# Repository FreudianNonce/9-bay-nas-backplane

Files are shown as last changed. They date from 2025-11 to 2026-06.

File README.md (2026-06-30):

# DIY 9-Bay NAS Backplane

> A simple and compact 9-Bay Backplance for a compact NAS application.

## Overview

This backplane is designed for connectivity for up to 8 SATA 3.0 storage drives connected to a PCIE HBA, as well as one slot for a SATA 3.0 boot drive connected to a motherboard SATA header. This board was specifically designed to be used in a Fractal Terra with an HDPLEX 250w GaN PSU, but should work for any small form factor NAS.

## Specifications

Dimensions: 115mmx58mm
Power Connector: 4-pin peripheral
Supply Voltage: 5v
Hot Swap: Hardware Supported (HBA must also support)

## Project Status

We've reached version 1.2 of this project. It took longer than I hoped, but I've built and tested this version and am currently running it in my NAS.

## Changes

Changes since version 1.0 include the following

- updated power connector to 4-pin peripheral (goodbye screw terminal)
- updated bulk capacitors to an appropriate size
- removed the 12v rail (only 5v is needed for SSDs)
- added full ground plane
- fixed SATA Data differential pair balancing
- added large isolation zone

## Making

Actually making one of these backplanes is very tedious. I can only recommend this if you have fine soldering skills.

If you do decide to make this, this is how I assembeled it.

- solder the SMD capacitors and resistors first. It is recommended that you use a solder reflow station. 
- for SATA interfaces, start on the end of the board that is furthest away from the power through holes
- use two 22-pin SATA connectors (one on J901 and one on J101, for balance), solder J901
- flip the board over and use three 7-pin SATA connectors (one on J902, J102, and the edge of the board where its falling over), solder J902
- flip the board over and repeat for all slots in descending order.
- once all the slots are soldered, solder the bulk capacitors, and 4-pin power. order doesnt matter here

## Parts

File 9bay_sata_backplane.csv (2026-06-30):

Reference | Qty | Value | DNP | Exclude from BOM | Exclude from Board | Footprint | Datasheet
C1,C2 | 2 | 25v 560uf |  |  |  | Capacitor_THT:CP_Radial_D10.0mm_P5.00mm | https://www.mouser.com/ProductDetail/Panasonic/EEH-AZS1E561B?qs=81r%252BiQLm7BR3Lrx9nkxErQ%3D%3D
C101,C201,C301,C401,C501,C601,C701,C801,C901 | 9 | 35v 10uf |  |  |  | Capacitor_SMD:C_1206_3216Metric | https://www.mouser.com/ProductDetail/Samsung-Electro-Mechanics/CL31B106KLHNNNE?qs=yOVawPpwOwktbQXOrUt5Og%3D%3D
J1 | 1 | HDD POWER |  |  |  | Connector_TE-Connectivity:TE_MATE-N-LOK_350211-1_1x04_P5.08mm_Vertical | https://www.mouser.com/ProductDetail/TE-Connectivity-AMP/350211-1
J101,J201,J301,J401,J501,J601,J701,J801,J901 | 9 | 87779-1001 |  |  |  | 87779-1001:877791001 | https://www.mouser.com/ProductDetail/Molex/87779-1001?qs=D%252By4jQJzx8JOwxiJNs7sKQ%3D%3D
J102,J202,J302,J402,J502,J602,J702,J802,J902 | 9 | 67800-8025 |  |  |  | 67800-8025:678008025 | https://www.mouser.com/ProductDetail/Molex/67800-8025?qs=3DzawVMofg92QkpdTaH6sA%3D%3D
R101,R201,R301,R401,R501,R601,R701,R801,R901 | 9 | 22ohm |  |  |  | Resistor_SMD:R_1206_3216Metric | https://www.mouser.com/ProductDetail/Panasonic/ERJ-U08F22R0V?qs=Z3CaLxJiOJIsu2tgjsUTiA%3D%3D

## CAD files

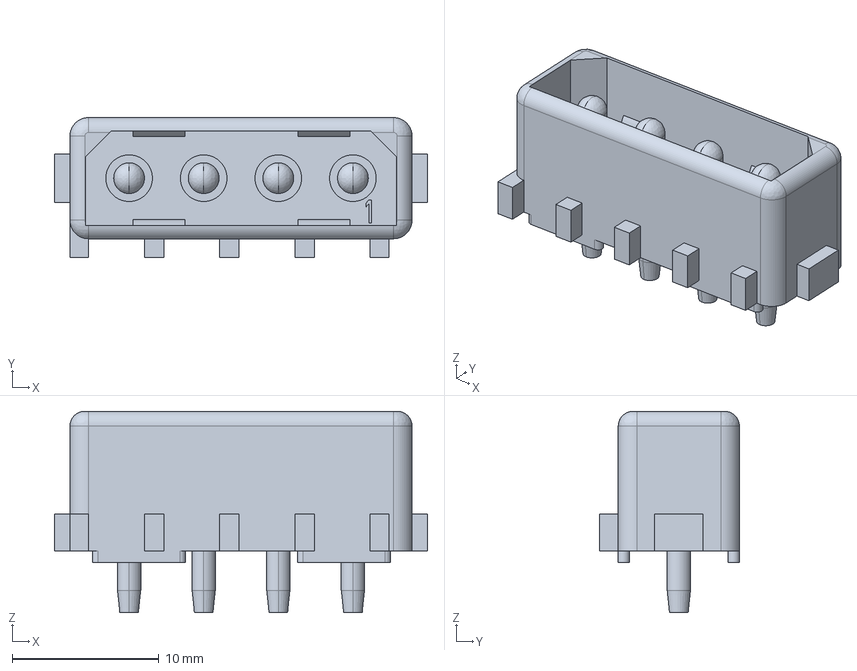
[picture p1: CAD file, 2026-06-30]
350211-1/c-350211-1-af-3d.stp
25.4 x 9.53 x 13.7 mm

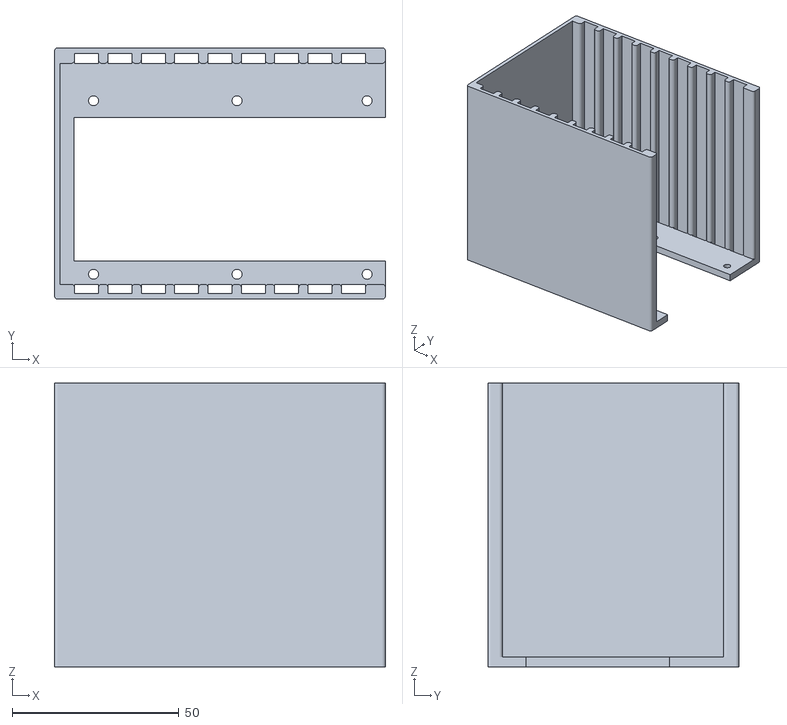
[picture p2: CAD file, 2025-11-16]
drive_cage/9-bay-nas-backplane-cage.stl
99.2 x 75.3 x 85.0

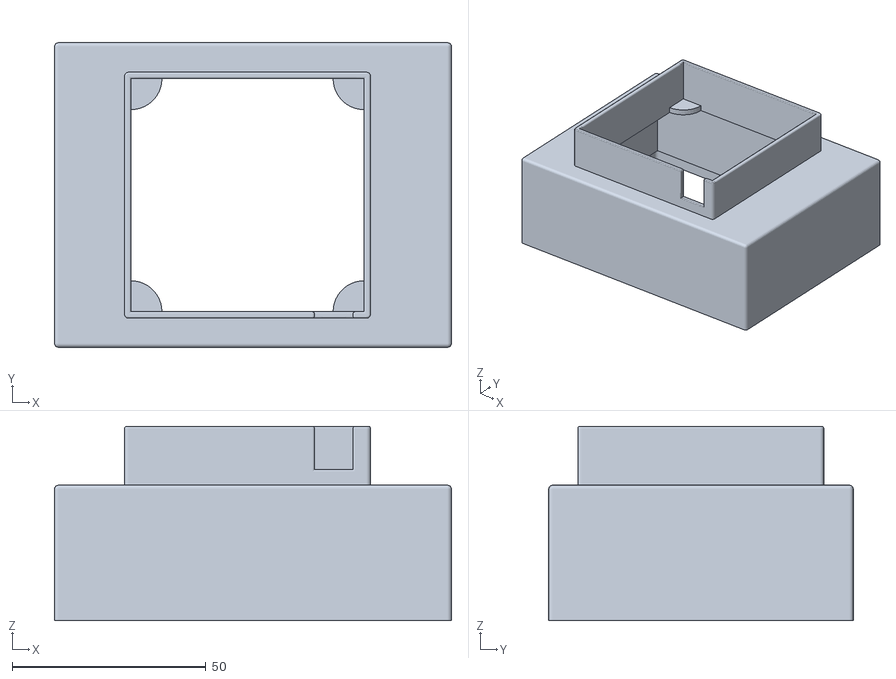
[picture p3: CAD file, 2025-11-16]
drive_cage/9-bay-nas-backplane-flume.stl
102.5 x 78.7 x 50.2

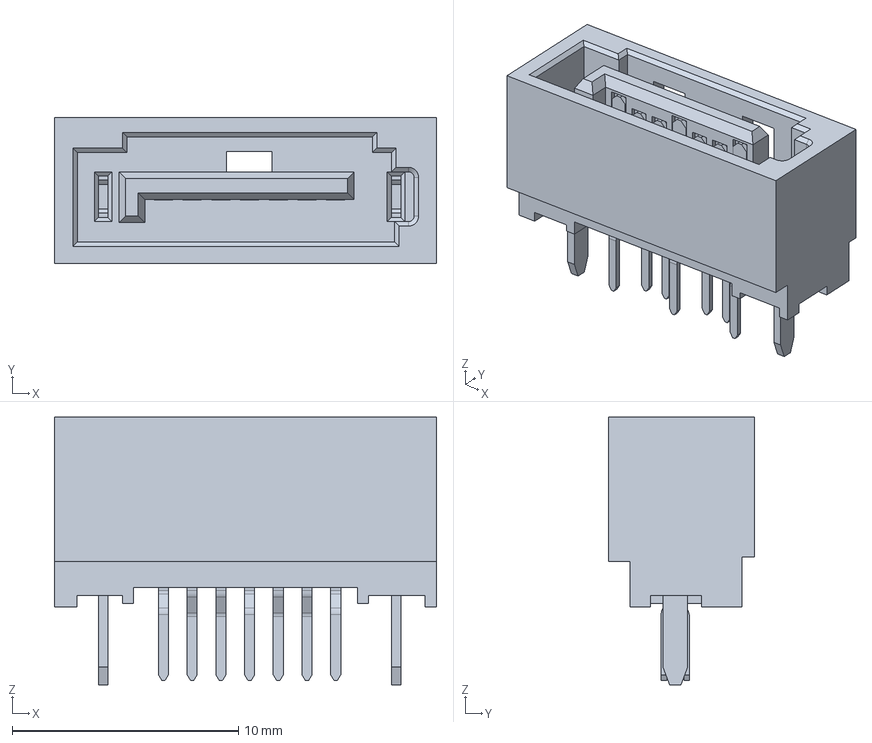
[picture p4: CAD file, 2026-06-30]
67800-8025/67800-8025.stp
16.9 x 6.45 x 11.9 mm

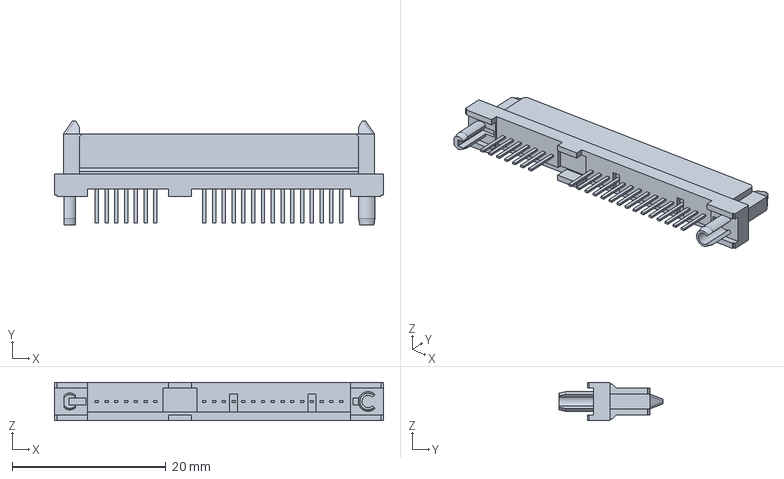
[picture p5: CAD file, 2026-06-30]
87779-1001/87779-1001.stp
42.7 x 13.6 x 5.00 mm

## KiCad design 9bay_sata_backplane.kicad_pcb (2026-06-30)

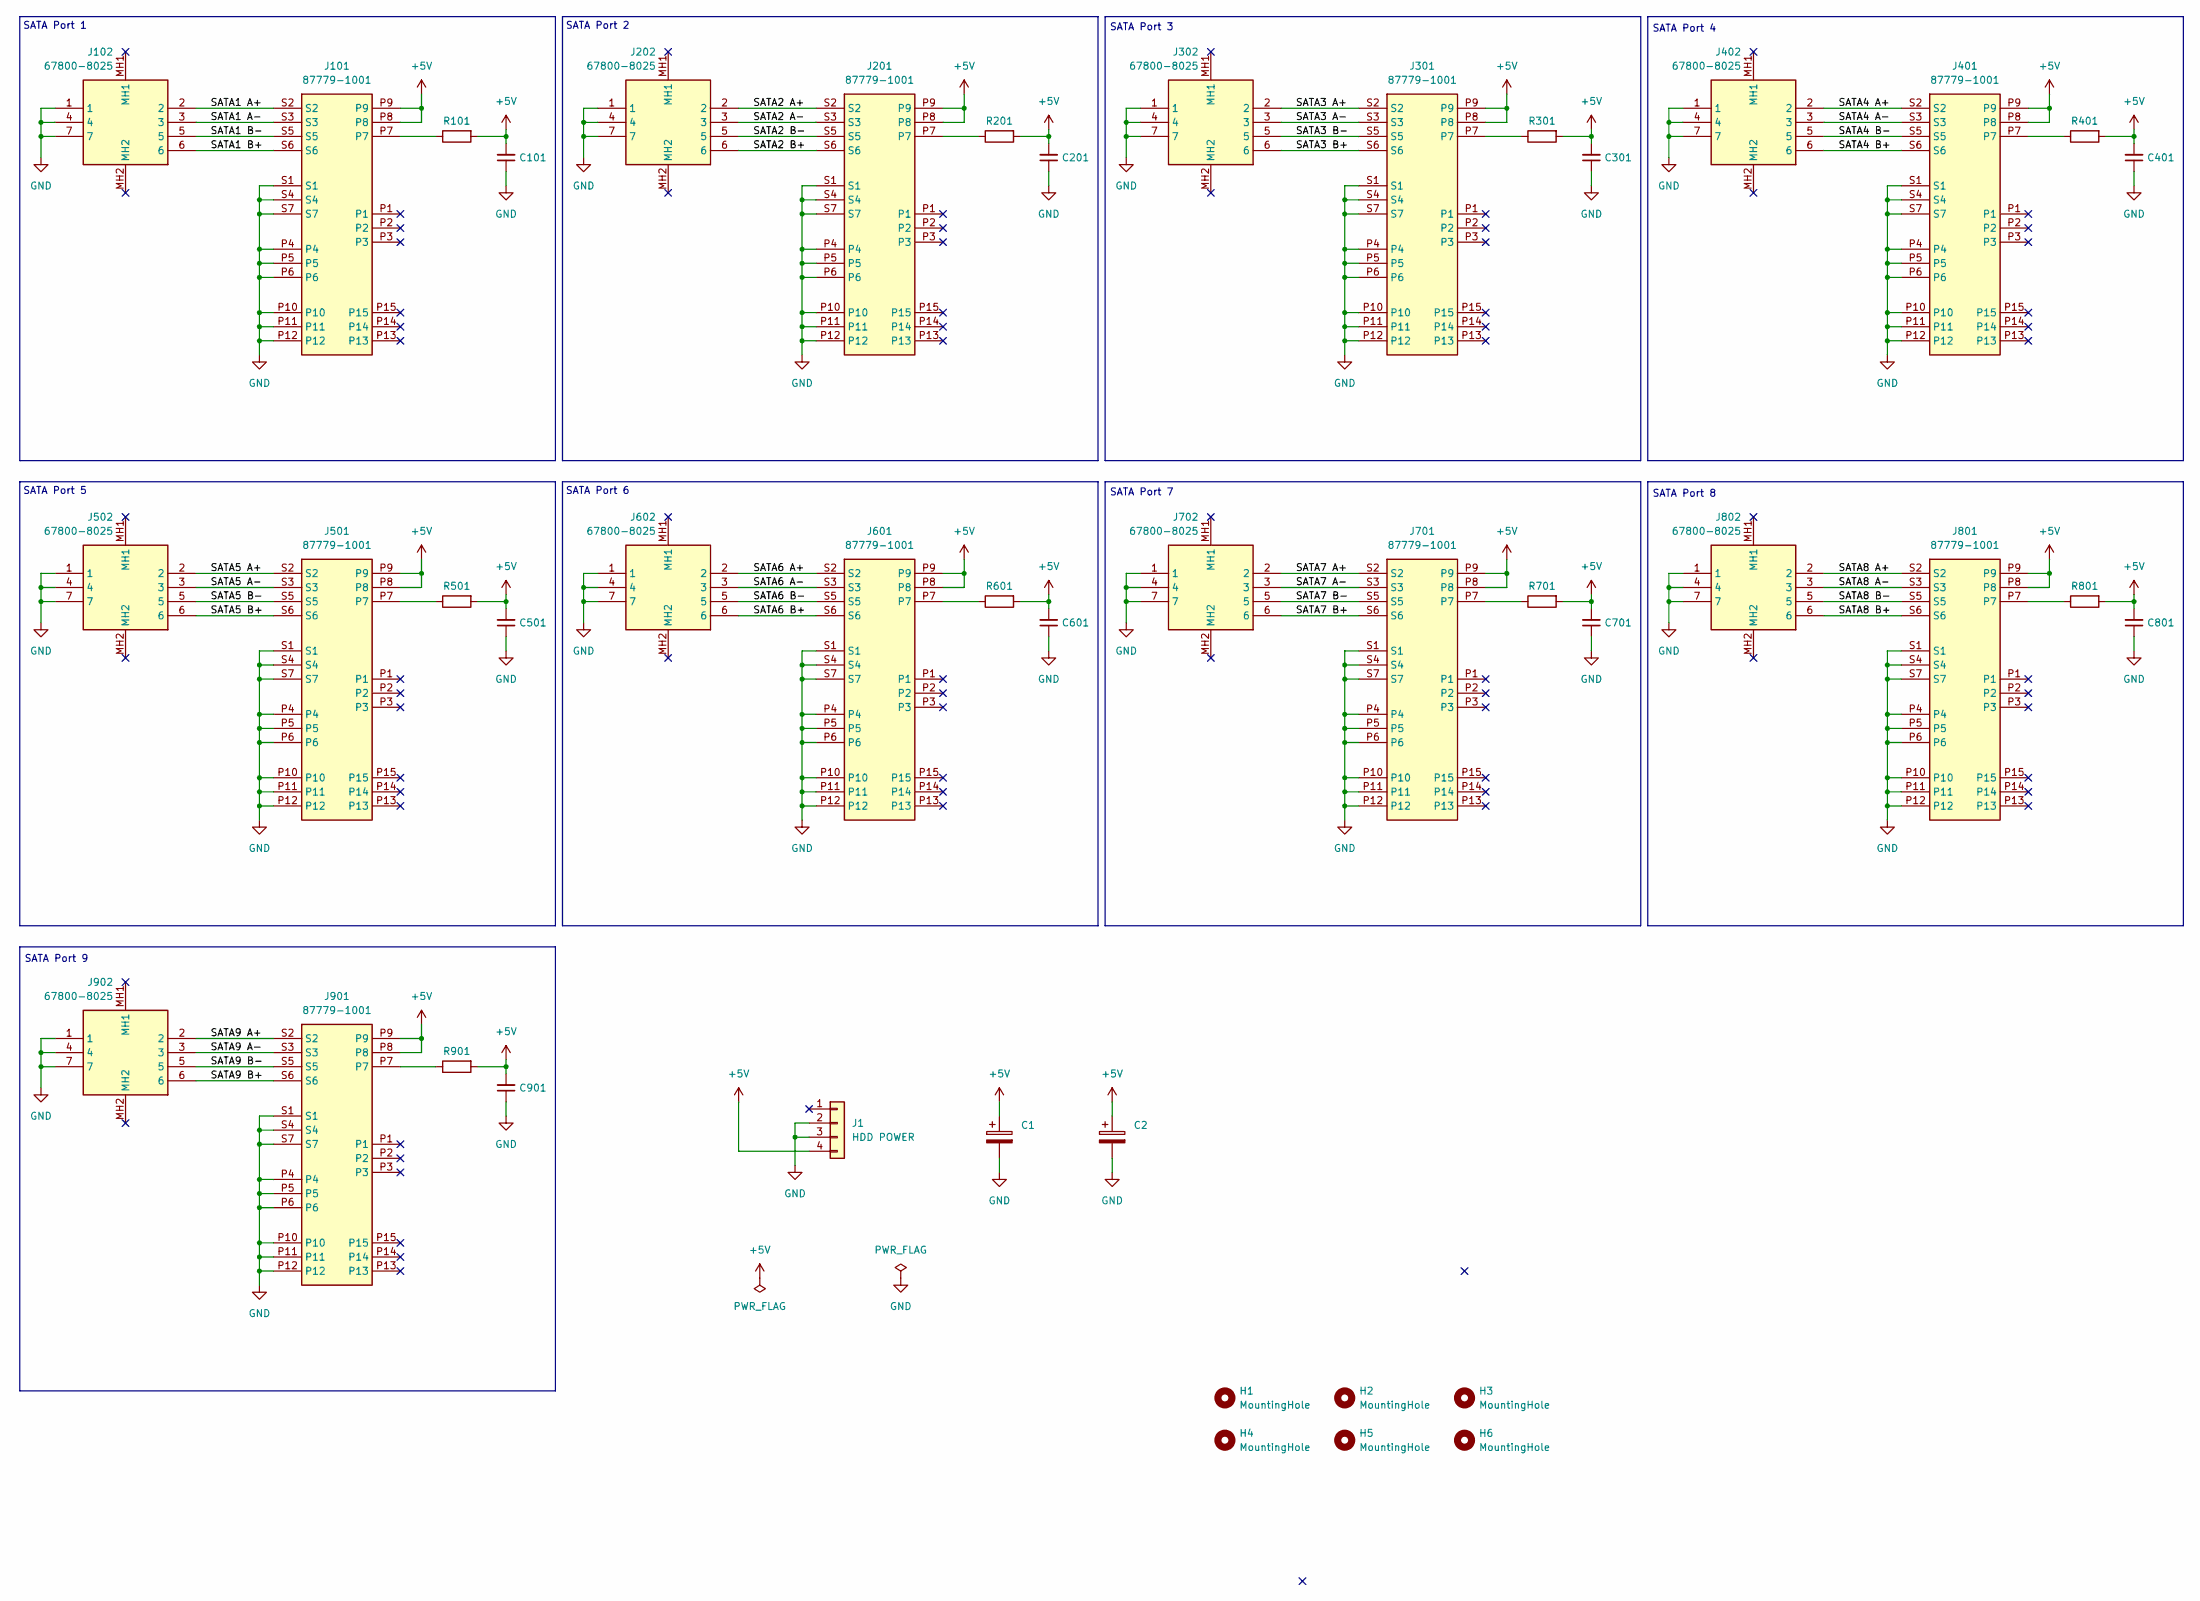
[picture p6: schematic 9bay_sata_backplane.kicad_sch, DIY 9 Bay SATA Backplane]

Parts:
C1, C2: 25v 560uf; CP_Radial_D10.0mm_P5.00mm
C101, C201, C301, C401, C501, C601, C701, C801, C901: 35v 10uf; C_1206_3216Metric
H1, H2, H3, H4, H5, H6: MountingHole; MountingHole_3mm
J1: HDD POWER; TE_MATE-N-LOK_350211-1_1x04_P5.08mm_Vertical
J101, J201, J301, J401, J501, J601, J701, J801, J901: 87779-1001; 877791001; Manufacturer_Part_Number 87779-1001; Mouser Part Number 538-87779-1001
J102, J202, J302, J402, J502, J602, J702, J802, J902: 67800-8025; 678008025; Manufacturer_Part_Number 67800-8025; Mouser Part Number 538-67800-8025
R101, R201, R301, R401, R501, R601, R701, R801, R901: 22ohm; R_1206_3216Metric

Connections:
+5V: C1.1, C2.1, C101.2, C201.2, C301.2, C401.2, C501.2, C601.2, C701.2, C801.2, C901.2, J1.4, J101.P8, J101.P9, J201.P8, J201.P9, J301.P8, J301.P9, J401.P8, J401.P9, J501.P8, J501.P9, J601.P8, J601.P9, J701.P8, J701.P9, J801.P8, J801.P9, J901.P8, J901.P9, R101.2, R201.2, R301.2, R401.2, R501.2, R601.2, R701.2, R801.2, R901.2
/SATA1 A+: J101.S2, J102.2
/SATA1 A-: J101.S3, J102.3
/SATA1 B+: J101.S6, J102.6
/SATA1 B-: J101.S5, J102.5
/SATA2 A+: J201.S2, J202.2
/SATA2 A-: J201.S3, J202.3
/SATA2 B+: J201.S6, J202.6
/SATA2 B-: J201.S5, J202.5
/SATA3 A+: J301.S2, J302.2
/SATA3 A-: J301.S3, J302.3
/SATA3 B+: J301.S6, J302.6
/SATA3 B-: J301.S5, J302.5
/SATA4 A+: J401.S2, J402.2
/SATA4 A-: J401.S3, J402.3
/SATA4 B+: J401.S6, J402.6
/SATA4 B-: J401.S5, J402.5
/SATA5 A+: J501.S2, J502.2
/SATA5 A-: J501.S3, J502.3
/SATA5 B+: J501.S6, J502.6
/SATA5 B-: J501.S5, J502.5
/SATA6 A+: J601.S2, J602.2
/SATA6 A-: J601.S3, J602.3
/SATA6 B+: J601.S6, J602.6
/SATA6 B-: J601.S5, J602.5
/SATA7 A+: J701.S2, J702.2
/SATA7 A-: J701.S3, J702.3
/SATA7 B+: J701.S6, J702.6
/SATA7 B-: J701.S5, J702.5
/SATA8 A+: J801.S2, J802.2
/SATA8 A-: J801.S3, J802.3
/SATA8 B+: J801.S6, J802.6
/SATA8 B-: J801.S5, J802.5
/SATA9 A+: J901.S2, J902.2
/SATA9 A-: J901.S3, J902.3
/SATA9 B+: J901.S6, J902.6
/SATA9 B-: J901.S5, J902.5
GND: C1.2, C2.2, C101.1, C201.1, C301.1, C401.1, C501.1, C601.1, C701.1, C801.1, C901.1, J1.2, J1.3, J101.P4, J101.P5, J101.P6, J101.P10, J101.P11, J101.P12, J101.S1, J101.S4, J101.S7, J102.1, J102.4, J102.7, J201.P4, J201.P5, J201.P6, J201.P10, J201.P11, J201.P12, J201.S1, J201.S4, J201.S7, J202.1, J202.4, J202.7, J301.P4, J301.P5, J301.P6, J301.P10, J301.P11, J301.P12, J301.S1, J301.S4, J301.S7, J302.1, J302.4, J302.7, J401.P4, J401.P5, J401.P6, J401.P10, J401.P11, J401.P12, J401.S1, J401.S4, J401.S7, J402.1, J402.4, J402.7, J501.P4, J501.P5, J501.P6, J501.P10, J501.P11, J501.P12, J501.S1, J501.S4, J501.S7, J502.1, J502.4, J502.7, J601.P4, J601.P5, J601.P6, J601.P10, J601.P11, J601.P12, J601.S1, J601.S4, J601.S7, J602.1, J602.4, J602.7, J701.P4, J701.P5, J701.P6, J701.P10, J701.P11, J701.P12, J701.S1, J701.S4, J701.S7, J702.1, J702.4, J702.7, J801.P4, J801.P5, J801.P6, J801.P10, J801.P11, J801.P12, J801.S1, J801.S4, J801.S7, J802.1, J802.4, J802.7, J901.P4, J901.P5, J901.P6, J901.P10, J901.P11, J901.P12, J901.S1, J901.S4, J901.S7, J902.1, J902.4, J902.7
unnamed: J101.P7, R101.1
unnamed: J201.P7, R201.1
unnamed: J301.P7, R301.1
unnamed: J401.P7, R401.1
unnamed: J501.P7, R501.1
unnamed: J601.P7, R601.1
unnamed: J701.P7, R701.1
unnamed: J801.P7, R801.1
unnamed: J901.P7, R901.1

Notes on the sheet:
SATA Port 9
SATA Port 8
SATA Port 6
SATA Port 7
SATA Port 2
SATA Port 5
SATA Port 4
SATA Port 3
SATA Port 1

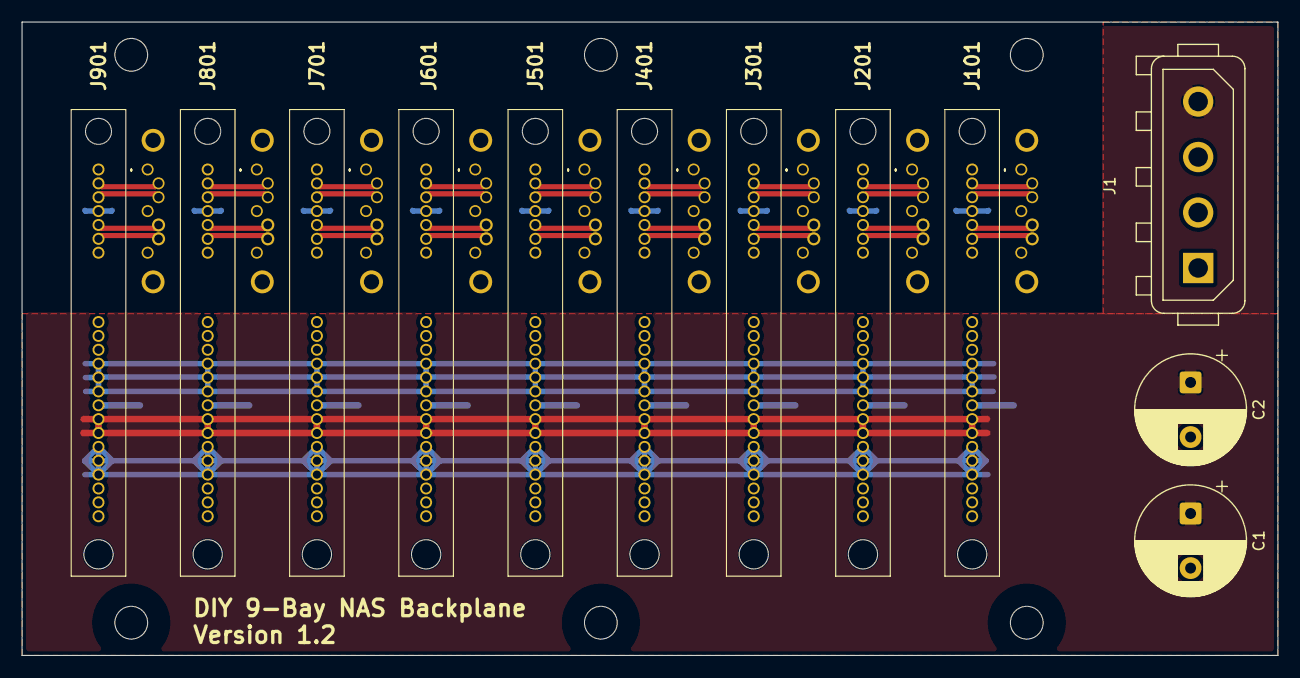
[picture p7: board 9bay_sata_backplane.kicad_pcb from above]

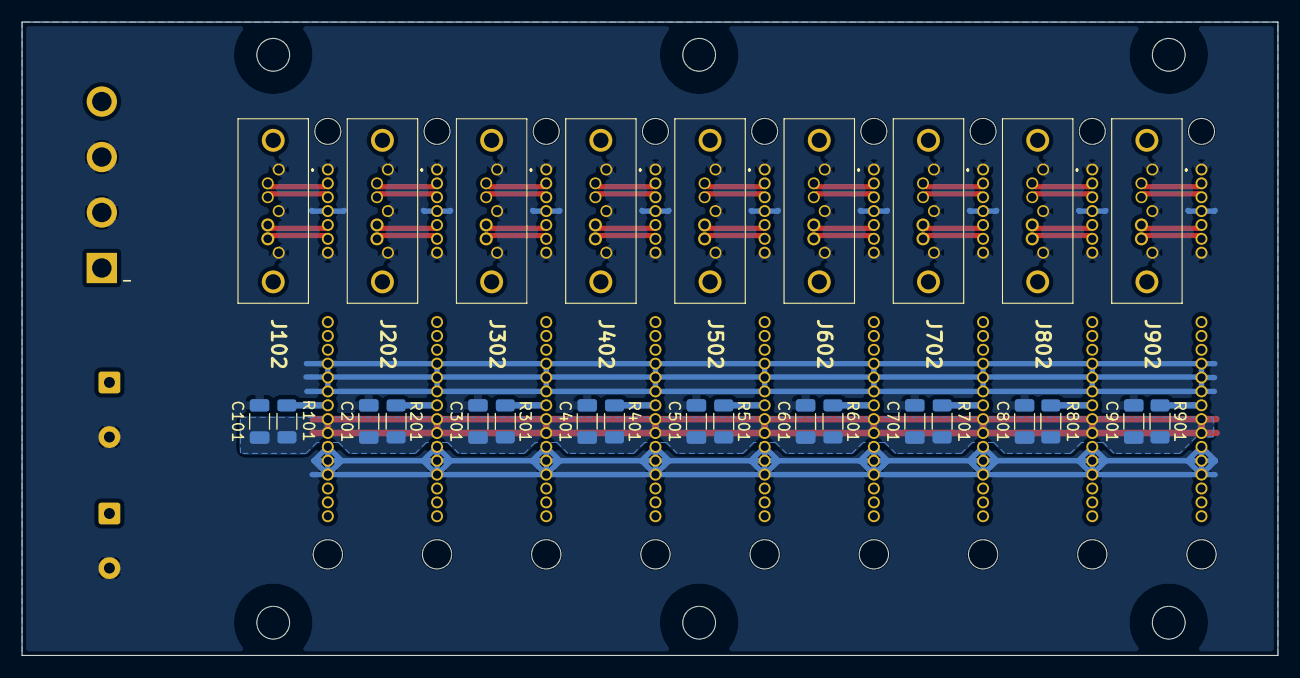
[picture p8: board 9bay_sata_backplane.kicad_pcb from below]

Board: 2 copper layers, 115.0 x 58.0 mm, 45 parts (27 on the bottom side), 47 nets.

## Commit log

2025-11-16 added drive cage 3d print
    [9-bay-nas-backplane-cage.stl, 9-bay-nas-backplane-flume.stl]
2026-06-30 DIY 9-Bay SATA Backplane v1.2
    [67800-8025.stp, 87779-1001.stp, 9bay_sata_backplane.csv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]
